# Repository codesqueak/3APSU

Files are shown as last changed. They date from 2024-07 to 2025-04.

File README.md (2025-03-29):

# Nascom 3A PSU

Nascom 3A PSU replica

## Introduction

This board is a form, fit and function replacement for the original Nascom 3A PSU.
Many of these boards are now showing their age and this is the perfect replacement for those wanting the original hardware.

Kicad View

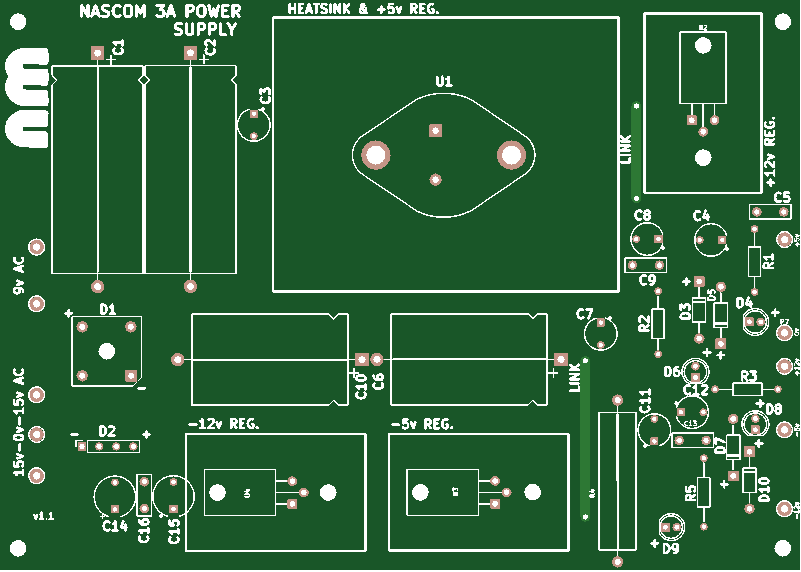
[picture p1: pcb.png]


Front PCB

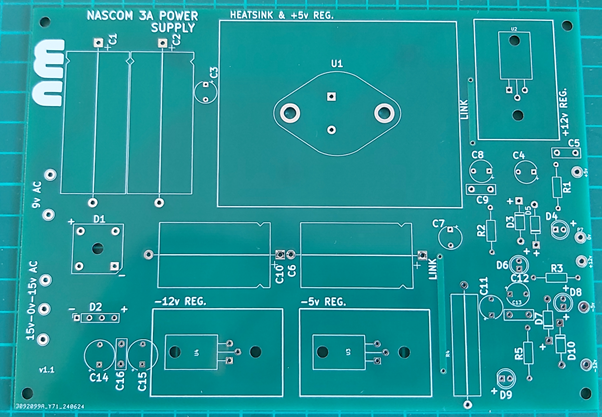
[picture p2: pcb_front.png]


Back PCB

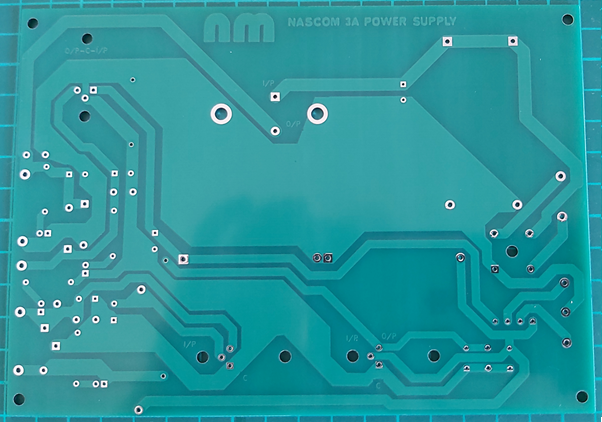
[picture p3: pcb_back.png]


Built PCB

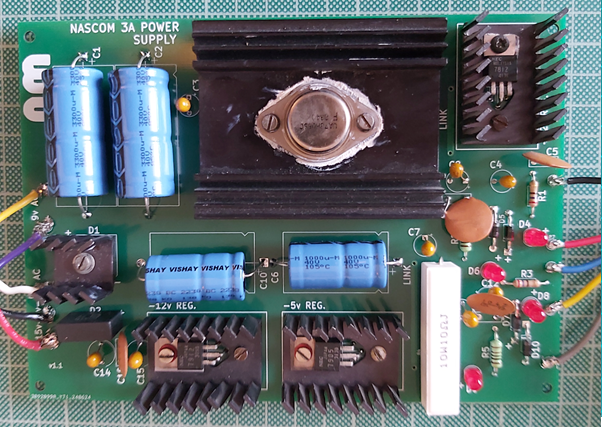
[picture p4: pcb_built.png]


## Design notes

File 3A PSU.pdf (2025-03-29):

3A PSU

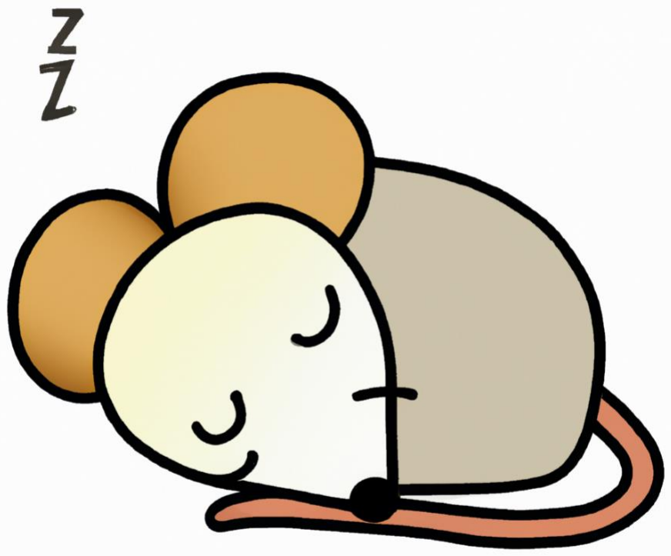
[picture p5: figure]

Issue 1.3 | Page 1 | 29-March-2025

## 3A Power Supply

### Instruction Manual & Construction Notes

Issue 1.3 | Page 2 | 29-March-2025

## Contents

Issue 1.3 | Page 3 | 29-March-2025

## 1 Introduction

This board is a form, fit and function replacement for the original Nascom 3A PSU.

Many of these boards are now showing their age and this is the perfect replacement for those wanting the original hardware.

Issue 1.3 | Page 4 | 29-March-2025

## 2 Components

Qty | Reference(s) | Value | Notes
2 | C1, C2 | 3300uF | Electrolytic
6 | C3, C4, C7, C8, C11, C12 | 2.2uF | Tantalum
4 | C5, C9, C13, C16 | 0.1uF | Disc
2 | C6, C10 | 1000uF | Electrolytic
2 | C14, C15 | 2.2uF | Tantalum
1 | D1 | Rectifier | KBPC602 _ heatsink
1 | D2 | Rectifier | BR81D
4 | D3, D5, D7, D10 | 1N4001
4 | D4, D6, D8, D9 | LED | LED
2 | P1, P2 | 9VAC | Power In
2 | P3, P5 | 15VAC | Power In
1 | P4 | GND | Power In
1 | P6 | +5V | Power Out
1 | P7 | 0V | Power Out
1 | P8 | +12V | Power Out
1 | P9 | -5V | Power Out
1 | P10 | -12V | Power Out
2 | R1, R3 | 270
1 | R2 | 1K
1 | R4 | 10 | 10W Ceramic
1 | R5 | 1K
1 | U1 | LM323K | +5V Regulator (3A) + heatsink
1 | U2 | L7812 | +12V Regulator + heatsink
1 | U3 | L7905 | -5V Regulator + heatsink
1 | U4 | L7912 | -12V Regulator + heatsink

Issue 1.3 | Page 5 | 29-March-2025

## 3 Notes on Components

All the components used have been selected at time of design to be readily available via commercial component suppliers.

Th original design has two wire links that allowed the board to be constructed as single sided design. These have been replaced with tracks.

However, through plate holes do exists so links could be added if required to give an original look.

Issue 1.3 | Page 6 | 29-March-2025

## 4 Construction

### 4.1 Before you start construction

Inspect the PCB for any visible signs of damage

Select your components:

- Tantalum capacitors can be temperamental. Make sure they are inserted with the correct polarity, are of good quality and are overrated voltage wise.

### 4.2 Order of construction

The suggested recommended order of construction is:

- Resistors (Not the large ceramic resistor)
- Diodes
- Tantalum capacitors
- LED’s
- Power pins
- Disc capacitors
- Bridge rectifiers
- Large electrolytic capacitors
- Voltage regulators & heatsinks
- D2 heatsink

### 4.3 Mounting Hardware - Warning

The heatsinks require through board mountings (screw/washer/nut). Once completed, verify that any mounting hardware does not touch any tracks.

### 4.4 Test Before Use – DO THIS!

Before attaching any hardware to the power supply, it is STRONGLY RECOMMENDED that he voltages at the +5v, -5v, +12v and -12v outputs are verified to be correct.

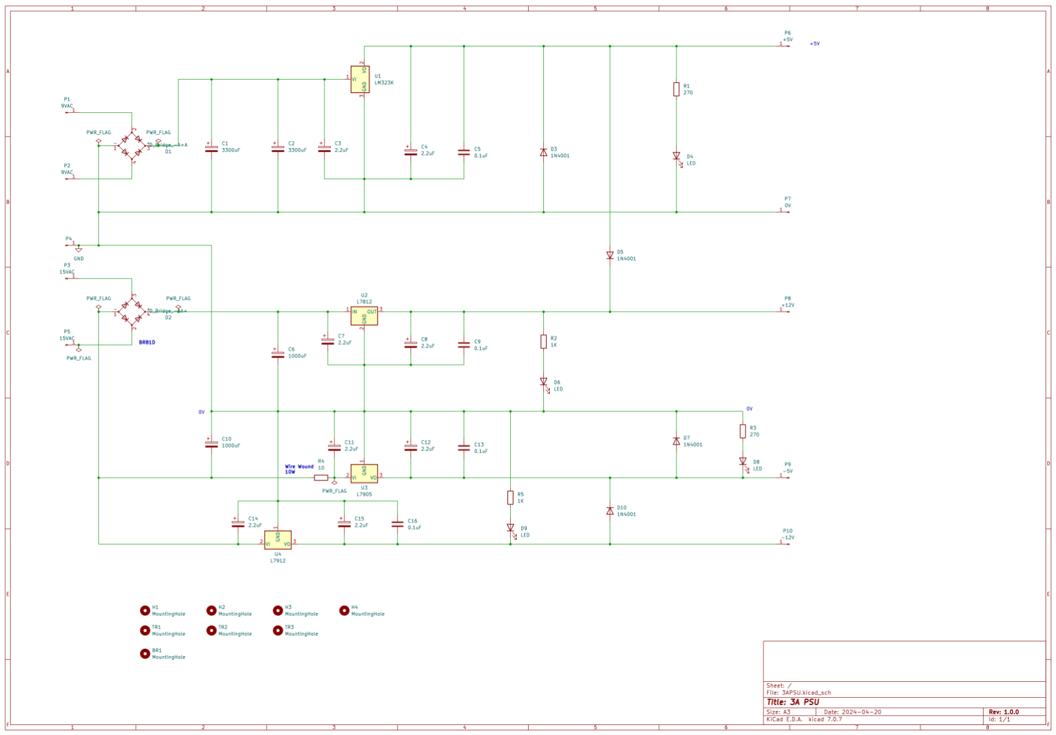
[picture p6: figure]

Issue 1.3 | Page 7 | 29-March-2025

Issue 1.3 | Page 8 | 29-March-2025

## 5 Errata

### 5.1 Version 1.1

The LED D9, has the +ve terminal marked on the incorrect through hole. The outline component silkscreen is correct.

### 5.2 Version 1.2

No functional change

### 5.3 Version 1.3

Update to Kicad 9. No functional change

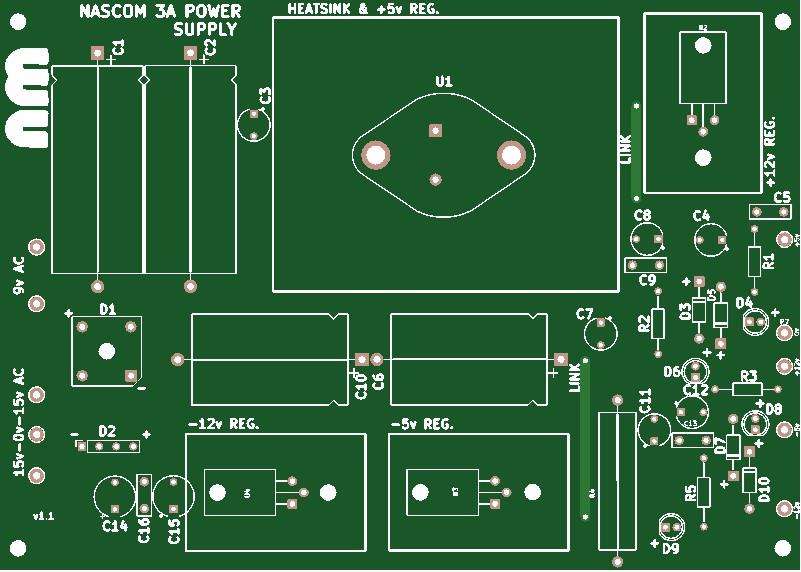
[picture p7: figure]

Issue 1.3 | Page 9 | 29-March-2025

## 6 Reference Images

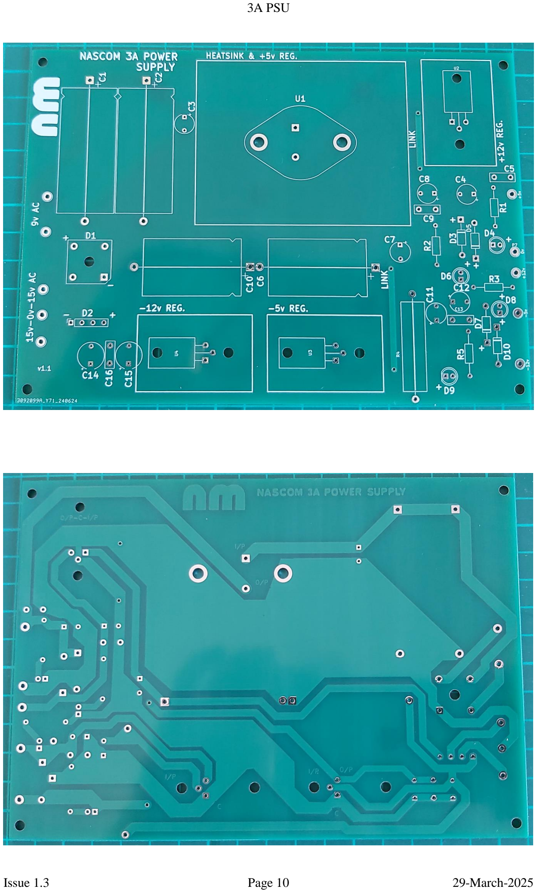
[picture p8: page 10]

Issue 1.3 | Page 10 | 29-March-2025

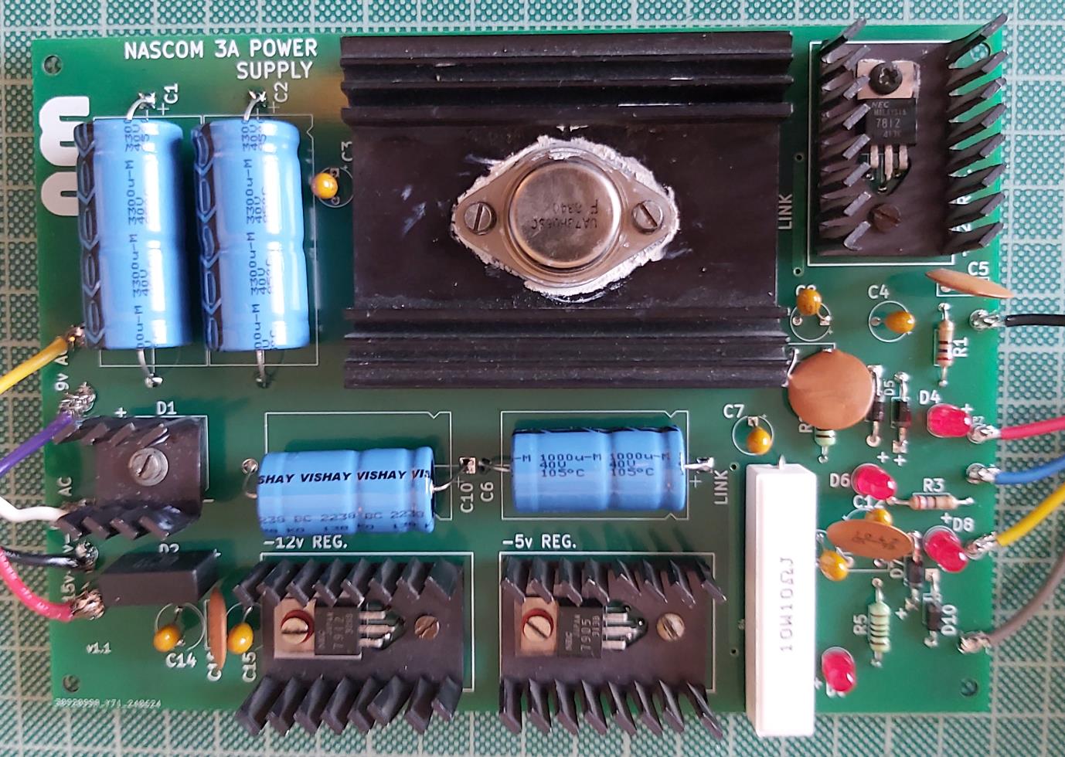
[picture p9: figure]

Issue 1.3 | Page 11 | 29-March-2025

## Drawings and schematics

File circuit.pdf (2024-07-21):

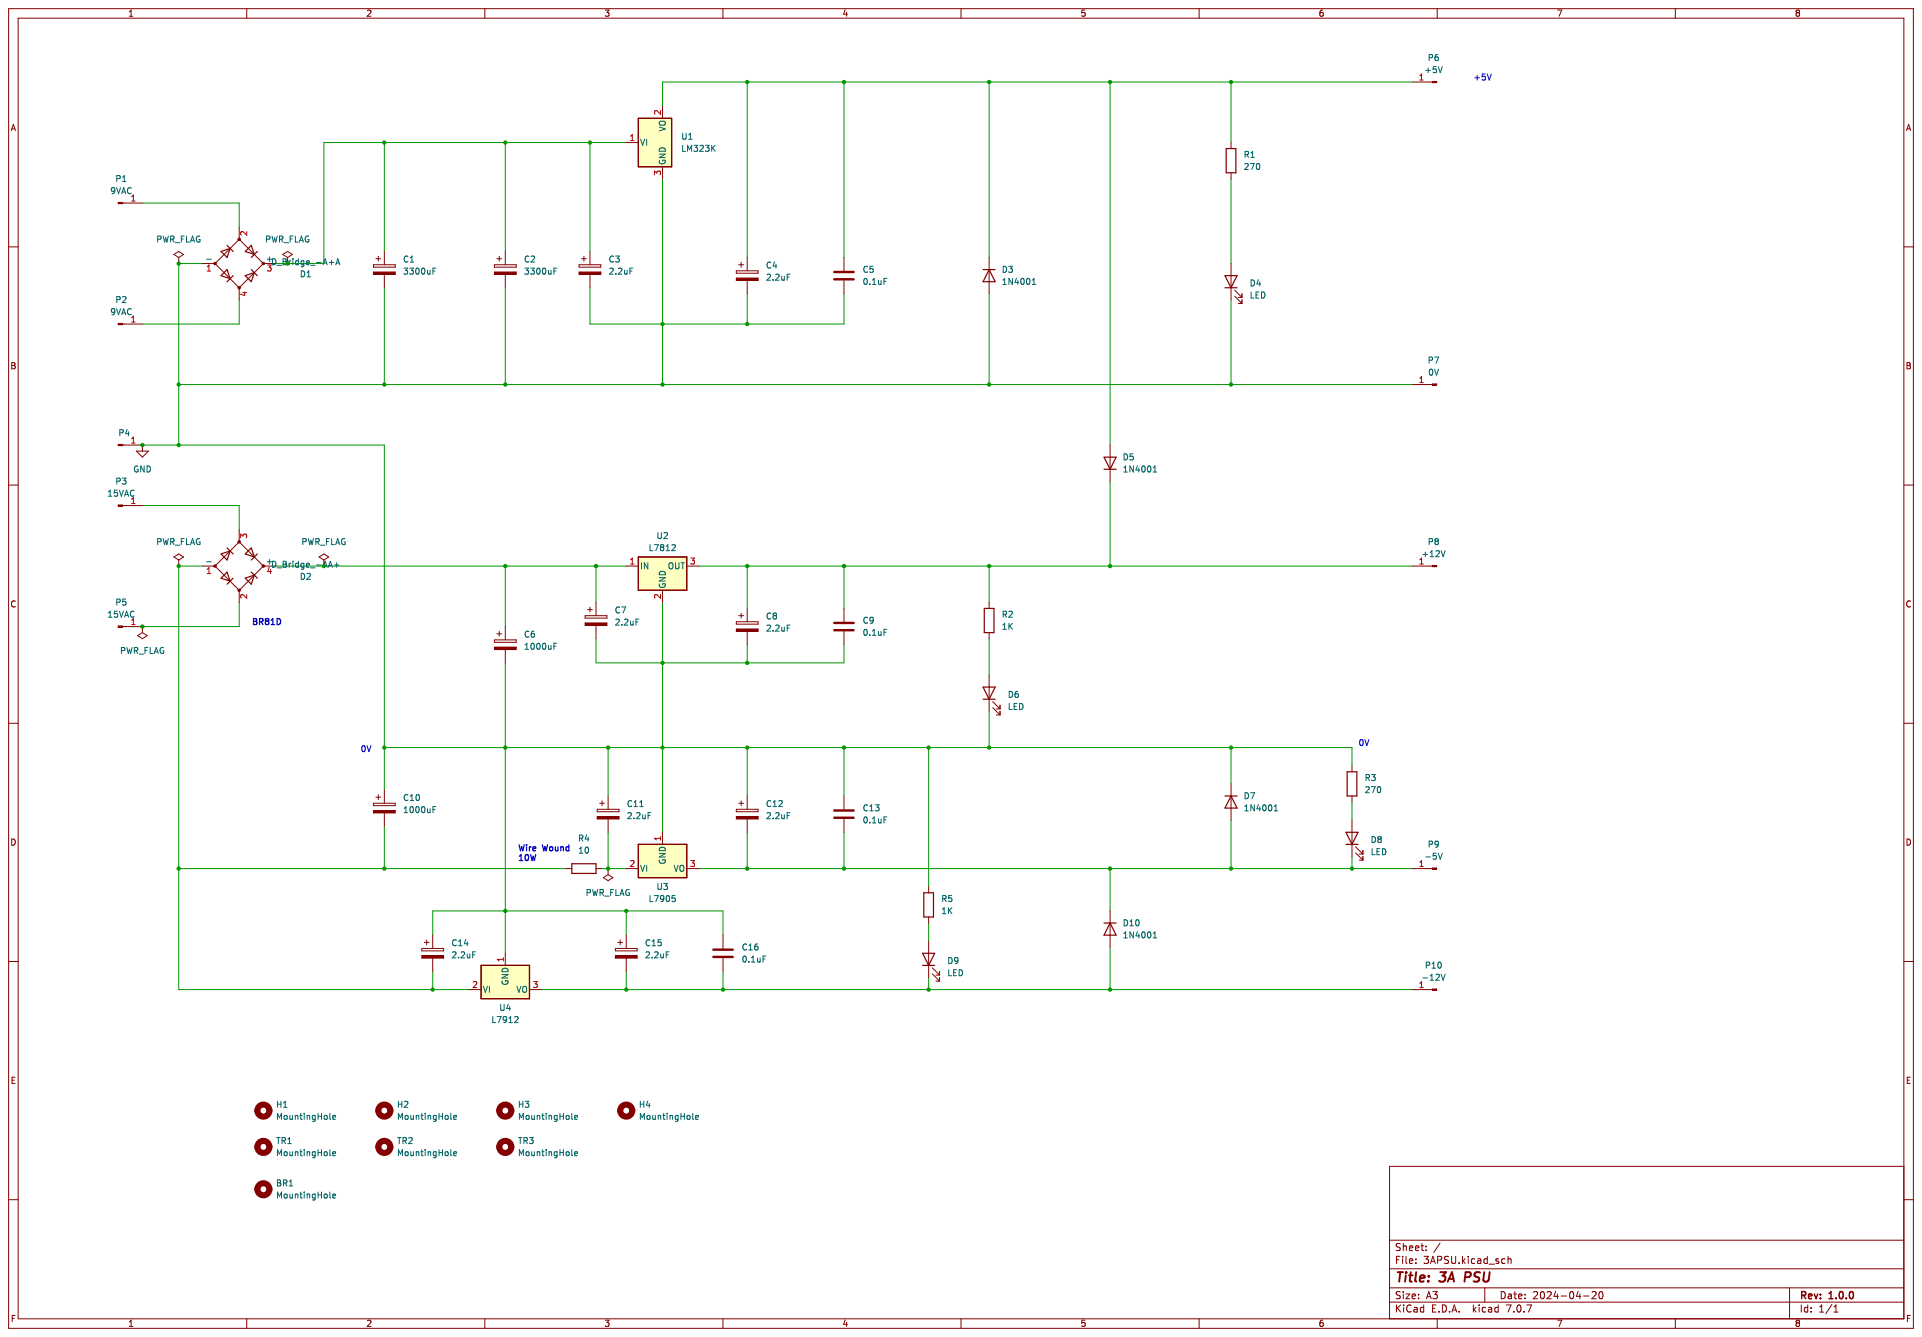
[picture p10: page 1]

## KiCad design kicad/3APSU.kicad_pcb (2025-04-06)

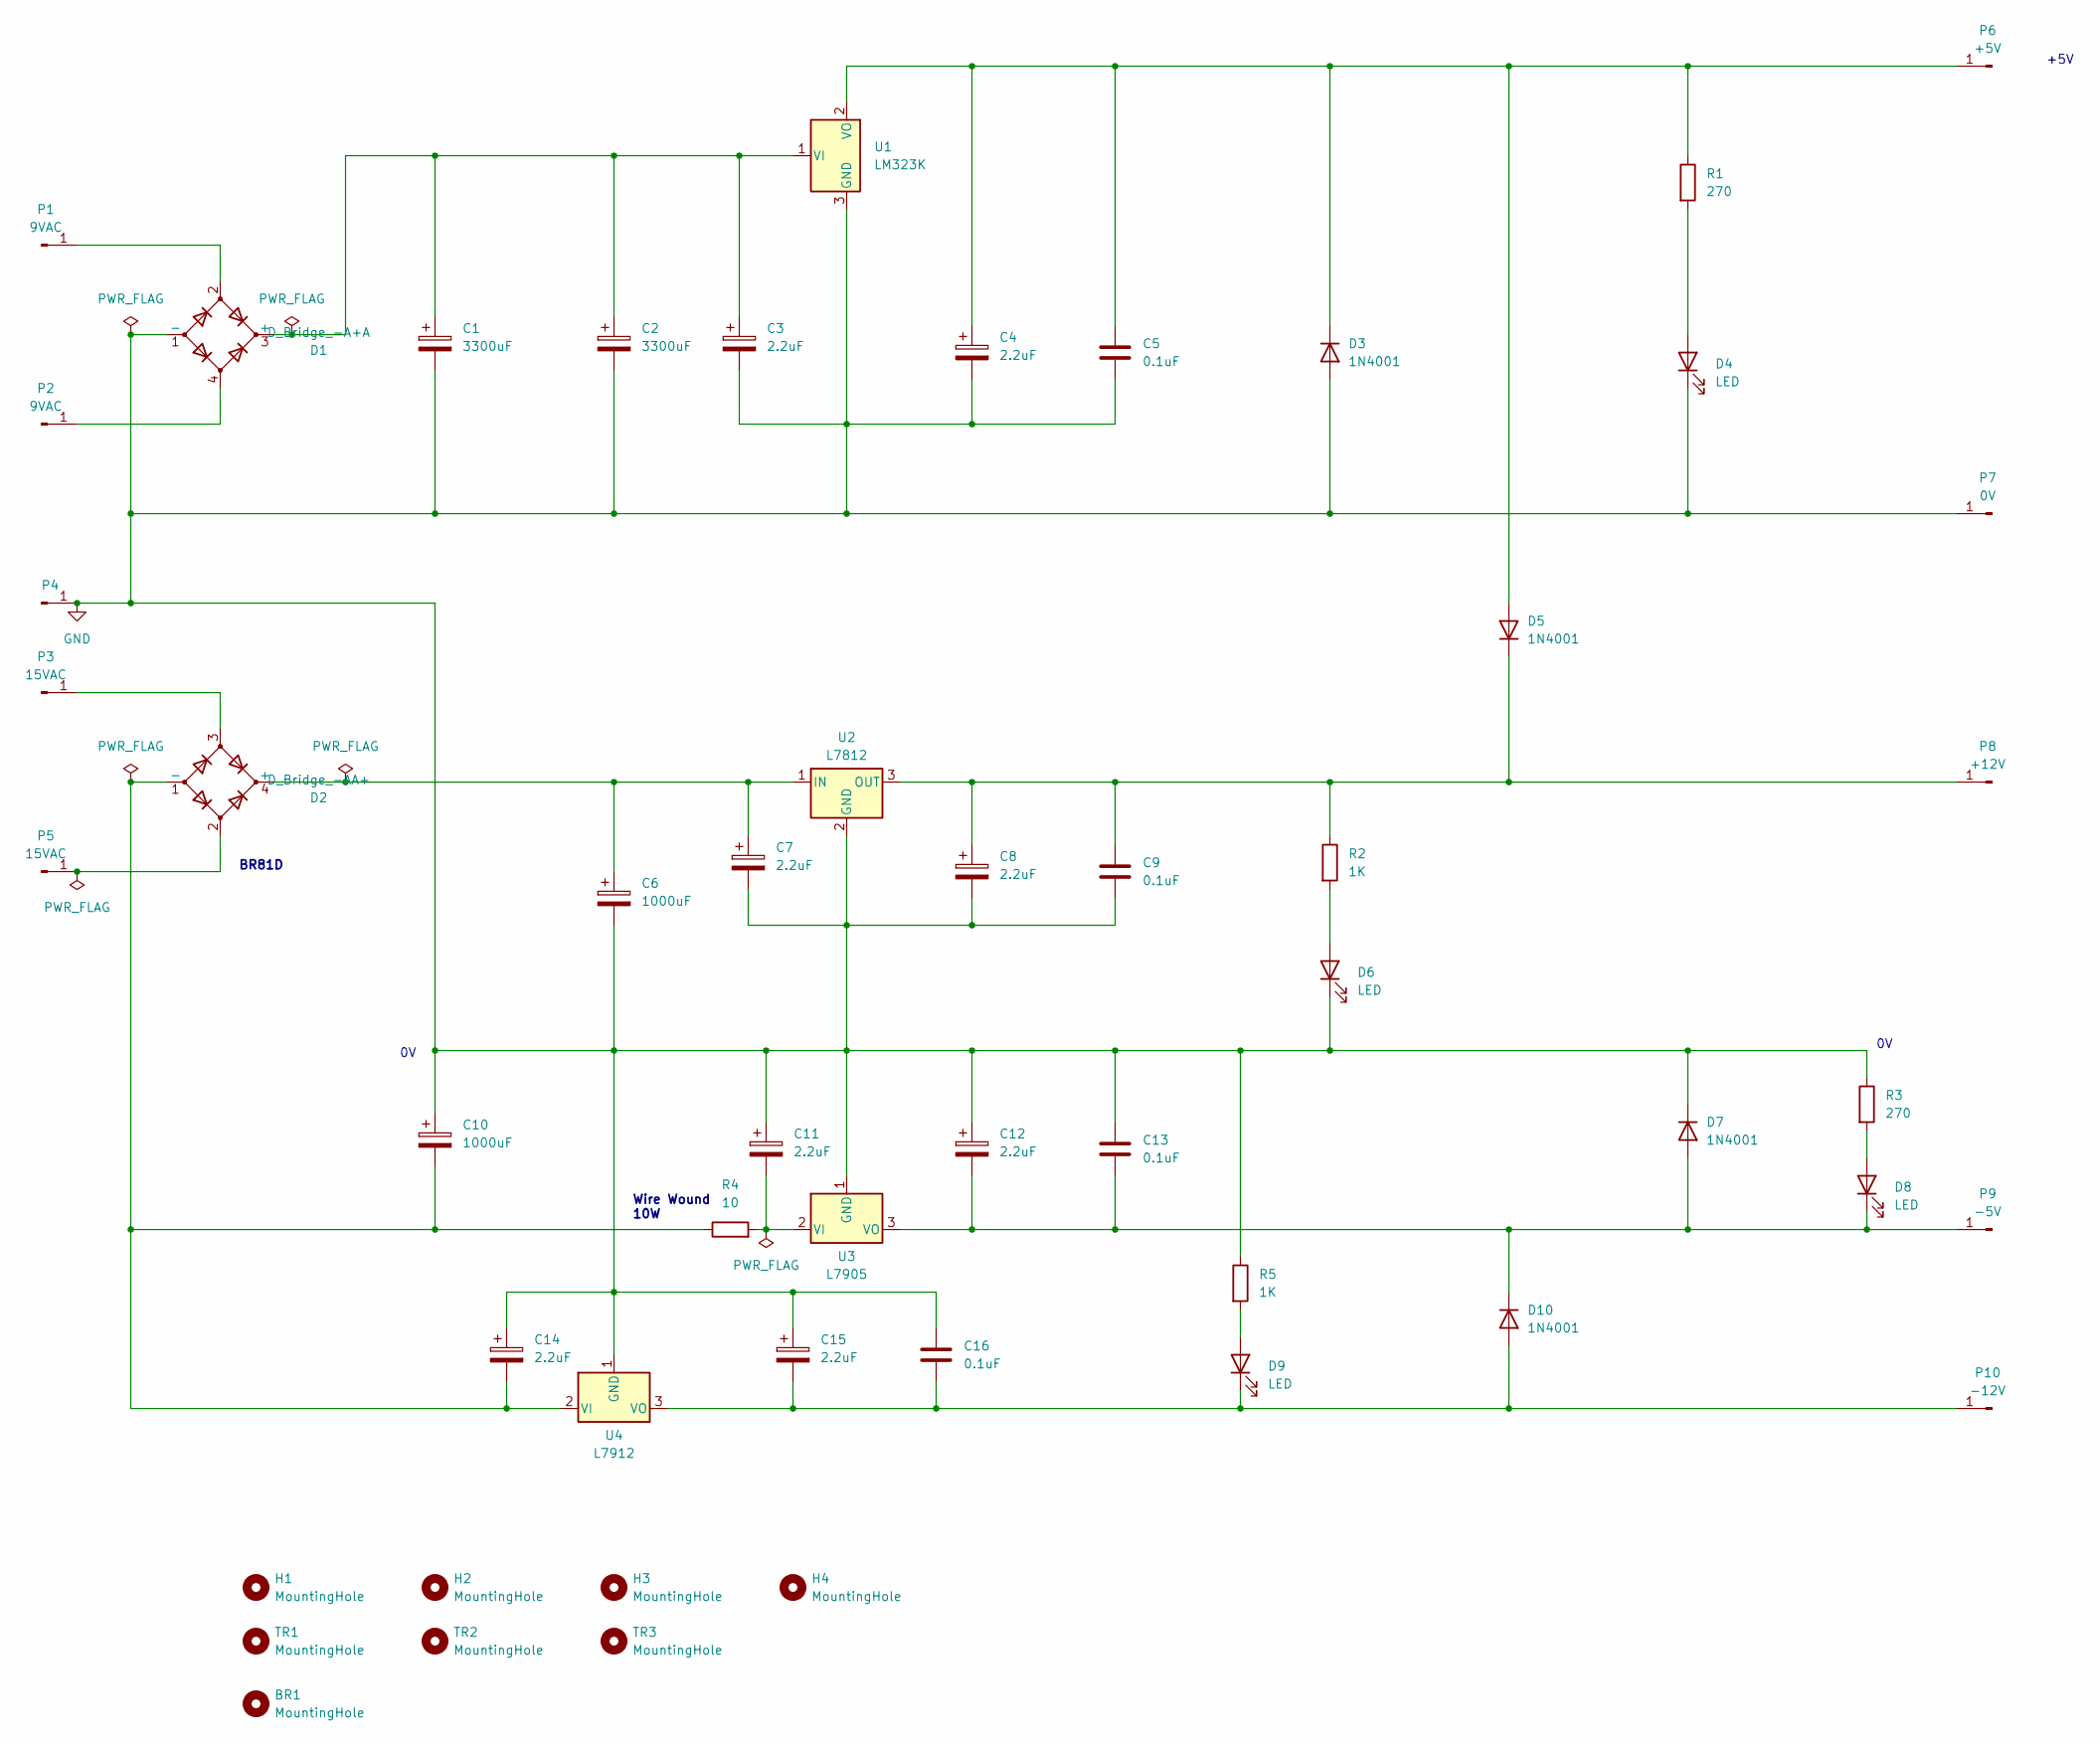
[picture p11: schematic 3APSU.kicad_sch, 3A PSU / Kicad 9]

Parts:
BR1: MountingHole; MountingHole_3.5mm
C1, C2: 3300uF; CP_Axial_L46.0mm_D20.0mm_P52.00mm_Horizontal
C3, C4, C7, C8, C11, C12: 2.2uF; CP_Radial_Tantal_D7.0mm_P5.00mm
C5, C9, C13, C16: 0.1uF; C_Disc_D9.0mm_W3.0mm_P6.00mm
C6, C10: 1000uF; CP_Axial_L34.5mm_D20.0mm_P41.00mm_Horizontal
C14, C15: 2.2uF; CP_Radial_Tantal_D8.0mm_P6.00mm
D1: D_Bridge_-A+A; Diode_Bridge_15.2x15.2x6.3mm_P10.9mm
D2: D_Bridge_-AA+; Bridge_Rectifier_BR81D
D3, D5, D7, D10: 1N4001; D_DO-41_SOD81_P12.70mm_Horizontal
D4, D6, D8, D9: LED; LED_D5.0mm
H1, H2, H3, H4: MountingHole; MountingHole_3.5mm
P1, P2: 9VAC; TestPoint_THTPad_D3.0mm_Drill1.5mm
P3, P5: 15VAC; TestPoint_THTPad_D3.0mm_Drill1.5mm
P4: GND; TestPoint_THTPad_D3.0mm_Drill1.5mm
P6: +5V; TestPoint_THTPad_D3.0mm_Drill1.5mm
P7: 0V; TestPoint_THTPad_D3.0mm_Drill1.5mm
P8: +12V; TestPoint_THTPad_D3.0mm_Drill1.5mm
P9: -5V; TestPoint_THTPad_D3.0mm_Drill1.5mm
P10: -12V; TestPoint_THTPad_D3.0mm_Drill1.5mm
R1, R3: 270; R_Axial_DIN0207_L6.3mm_D2.5mm_P14mm_Horizontal
R2: 1K; R_Axial_DIN0207_L6.3mm_D2.5mm_P14mm_Horizontal
R4: 10; R_Axial_Power_L31.0mm_W8.0mm_P36mm
R5: 1K; R_Axial_DIN0207_L6.3mm_D2.5mm_P15.24mm_Horizontal
TR1, TR2, TR3: MountingHole; MountingHole_3.5mm
U1: LM323K; TO-3
U2: L7812; TO-220-3_Horizontal_TabDown_staggered
U3: L7905; TO-220-3_Horizontal_TabDown_staggered
U4: L7912; TO-220-3_Horizontal_TabDown_staggered

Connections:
GND: C1.2, C2.2, C3.2, C4.2, C5.2, C6.2, C7.2, C8.2, C9.2, C10.1, C11.1, C12.1, C13.1, C14.1, C15.1, C16.1, D1.1 (-), D3.2 (A), D4.1 (K), D6.1 (K), D7.1 (K), P4.1, P7.1, R3.1, R5.1, U1.3 (GND), U2.2 (GND), U3.1 (GND), U4.1 (GND)
unnamed: C1.1, C2.1, C3.1, D1.3 (+), U1.1 (VI)
unnamed: C6.1, C7.1, D2.4 (+), U2.1 (IN)
unnamed: C10.2, C14.2, D2.1 (-), R4.1, U4.2 (VI)
unnamed: C4.1, C5.1, D3.1 (K), D5.2 (A), P6.1, R1.1, U1.2 (VO)
unnamed: D4.2 (A), R1.2
unnamed: C8.1, C9.1, D5.1 (K), P8.1, R2.1, U2.3 (OUT)
unnamed: D6.2 (A), R2.2
unnamed: D8.2 (A), R3.2
unnamed: D9.2 (A), R5.2
unnamed: C15.2, C16.2, D9.1 (K), D10.2 (A), P10.1, U4.3 (VO)
unnamed: C12.2, C13.2, D7.2 (A), D8.1 (K), D10.1 (K), P9.1, U3.3 (VO)
unnamed: D1.2, P1.1
unnamed: D1.4, P2.1
unnamed: D2.3, P3.1
unnamed: D2.2, P5.1
unnamed: C11.2, R4.2, U3.2 (VI)

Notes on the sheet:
Wire Wound 10W
+5V
BR81D

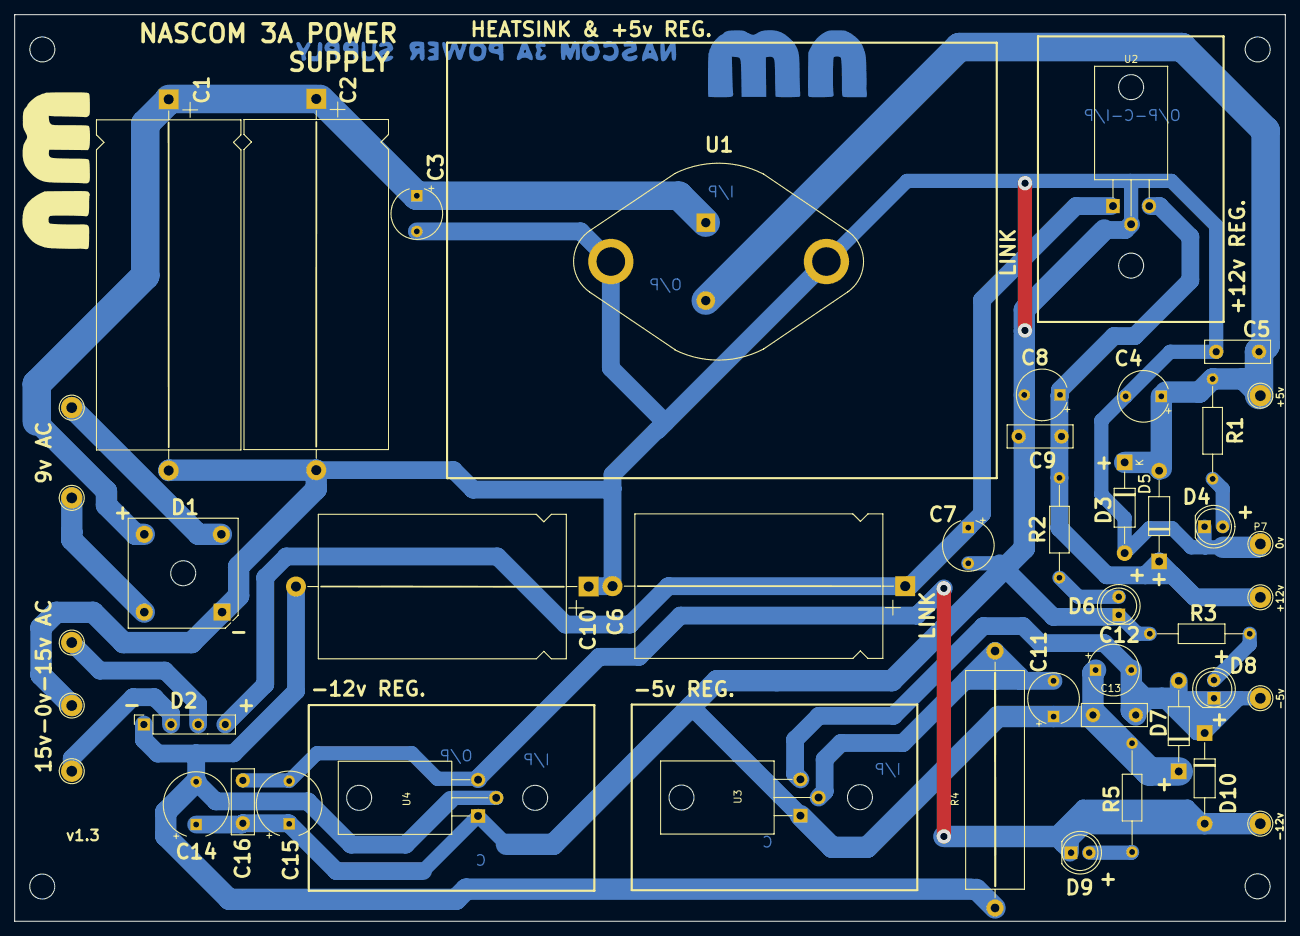
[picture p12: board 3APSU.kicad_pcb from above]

Board: 2 copper layers, 178.0 x 127.0 mm, 55 parts (0 on the bottom side), 17 nets.

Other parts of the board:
G001: LOGO; nm logo
G002: LOGO; psu long logo inverted back copper

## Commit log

2024-07-21 First upload
    [3APSU.kicad_pcb, 3APSU.kicad_sch]
2025-03-29 Kicad 9 update
    [3APSU.kicad_pcb, 3APSU.kicad_sch]
2025-04-06 Add code
    [3APSU.kicad_pcb]
